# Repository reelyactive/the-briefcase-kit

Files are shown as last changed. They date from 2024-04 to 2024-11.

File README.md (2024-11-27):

The Briefcase Kit
=================

[The Briefcase Kit](https://www.reelyactive.com/the-briefcase-kit/).

IoT Infrastructure and Middleware
---------------------------------

| Device | Technology | Middleware | Tutorial | 
|:---|:---|:---|:---|
| Aruba AP-X05 | BLE & WiFi & EnOcean | [barnowl-aruba](https://github.com/reelyactive/barnowl-aruba) | [Configuration Guide](https://reelyactive.github.io/diy/aruba-instant-config/) |
| Raspberry Pi CM4 | BLE | [barnowl-hci](https://github.com/reelyactive/barnowl-hci) | [Configuration Guide](https://reelyactive.github.io/diy/pareto-anywhere-pi/) |
| Impinj R700 | RAIN RFID | [barnowl-impinj](https://github.com/reelyactive/barnowl-impinj) | [Configuration Guide](https://reelyactive.github.io/diy/impinj-r700-config/) |

EnOcean Alliance devices are supported through a USB dongle connected to the Aruba AP.

# In this Repo:

- /hardware: Guides and digital assets for creation of The Briefcase Kit.

License
-------

MIT License

Copyright (c) 2024 [reelyActive](https://www.reelyactive.com)

Permission is hereby granted, free of charge, to any person obtaining a copy of this software and associated documentation files (the "Software"), to deal in the Software without restriction, including without limitation the rights to use, copy, modify, merge, publish, distribute, sublicense, and/or sell copies of the Software, and to permit persons to whom the Software is furnished to do so, subject to the following conditions:

The above copyright notice and this permission notice shall be included in all copies or substantial portions of the Software.

THE SOFTWARE IS PROVIDED "AS IS", WITHOUT WARRANTY OF ANY KIND, EXPRESS OR 
IMPLIED, INCLUDING BUT NOT LIMITED TO THE WARRANTIES OF MERCHANTABILITY, 
FITNESS FOR A PARTICULAR PURPOSE AND NONINFRINGEMENT. IN NO EVENT SHALL THE 
AUTHORS OR COPYRIGHT HOLDERS BE LIABLE FOR ANY CLAIM, DAMAGES OR OTHER 
LIABILITY, WHETHER IN AN ACTION OF CONTRACT, TORT OR OTHERWISE, ARISING FROM, 
OUT OF OR IN CONNECTION WITH THE SOFTWARE OR THE USE OR OTHER DEALINGS IN 
THE SOFTWARE.

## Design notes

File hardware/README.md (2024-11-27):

# The Briefcase Kit: Hardware Files

This folder contains files useful for the creation of the hardware for the briefcase kit:

## Bill of Materials

| Component | Qty | Distributor | Part number | 
|:---|:----|:---|:---|
| Low-Profile Binding Barrel and Screw | 8 | McMaster-Carr | [93813A317](https://www.mcmaster.com/93813A317/) |
| Low-Profile Binding Barrel and Screw | 16  | McMaster-Carr | [93813A325](https://www.mcmaster.com/93813A325/) |
| Rounded Head Screw | 22  | McMaster-Carr | [98685A710](https://www.mcmaster.com/98685A710/) |
| Nylon-Coated 1/2" Strapping | <1  | Home Depot | [1000178843](https://www.homedepot.ca/product/dahl-all-round-strapping-nylon-coated-1-2-inch-x-25-feet/1000178843) |

## Hardware Case Vector Files

- nanukCasePanels.ai/dxf/svg : Vector graphics, at scale, of the case's false bottom and upper rim. Suitable for laser cutter or CNC machine. DXF, SVG, and AI files are the same.

## Assembly Notes

- We recommend using .25" (6mm) HDPE for the panels, as it is a good combination of strength and flexibility. Most laser cutter operations will not want to cut HDPE, so you'll need to use a CNC machine to cut the panels if you use this material. If you want to use a laser cutter, .25" (6mm) wood is recommended over acrylic, as acrylic will likely be too brittle for this purpose. 

- Most of the work is assembling the false bottom, with the components attached to it, and the wires successfully tucked underneath for the cleanest look. The half-circle holes on the sides of the false bottom are for passing wires from the devices, so they traverse underneath the false bottom. 

- We've used extra-strong velco to attach the power supply components under the false bottom, and it has worked well.

- The current assembly process involves a lot of screws on the upper lip piece, I reommend panhead screws for the best look. However, this means if you need to make modifications to the assembly on the false bottom, there are a lot of screws to undo. Therefore, double check your wiring before screwing the upper lip in place.

## Resources

- There's a 3D model of the Nanuk 935  case here, which we used for modeling the false bottom and other panels: https://nanukcases.ca/products/nanuk-935#downloads

- A 3d model for the IMPINJ R700 is here: [IMPINJ R700](https://impinj.sharepoint.com/sites/CustomerSupport/Shared%20Documents/Forms/AllItems.aspx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), but this model is too complex for printing, so I made a simplified, but size-accurate version which can be found in this folder, as IMPINJRemodeled.stl.

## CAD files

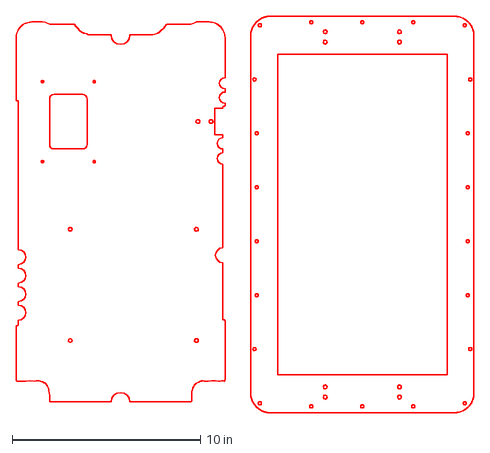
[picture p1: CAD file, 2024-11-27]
hardware/nanukCasePanels.dxf
24.3 x 21.1 in

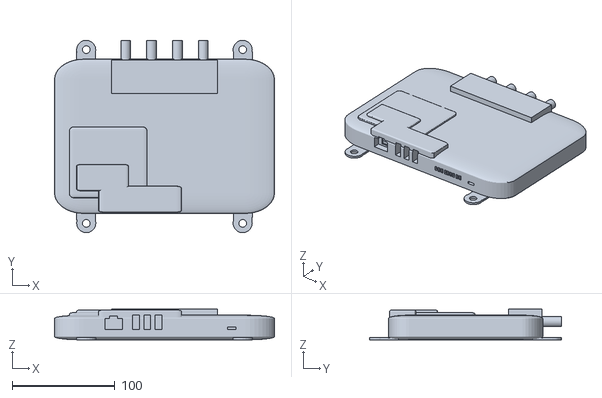
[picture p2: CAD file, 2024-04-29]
hardware/IMPINJRemodeled.stl
214.0 x 187.2 x 29.9

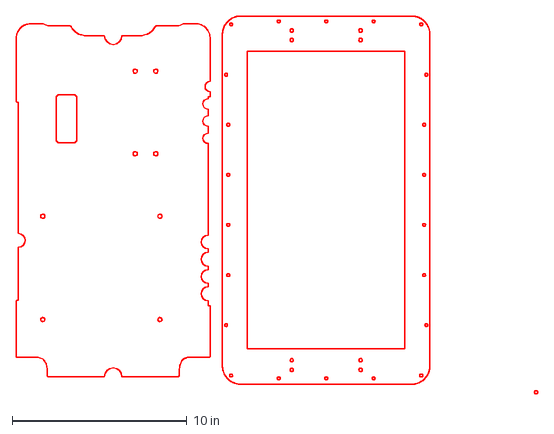
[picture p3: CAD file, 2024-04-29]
hardware/nanukCaseV1Panels.dxf
29.8 x 21.6 in

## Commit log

2024-04-29 first commit of files
    [nanukCaseV1Panels.dxf]
2024-04-29 more files added
    [IMPINJRemodeled.stl]
2024-11-27 added uploaded panel design as ai, dxf, svg.
    added uploaded panel design as ai, dxf, svg.
    Removed the old versions.
    Also added the BOM file as a PDF.
    [nanukCasePanels.dxf]
2024-11-27 Migrated relevant BOM elements to README
